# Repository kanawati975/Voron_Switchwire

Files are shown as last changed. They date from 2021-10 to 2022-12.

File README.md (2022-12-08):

# VORON SWITCHWIRE
## This is a Conversion **and** few Upgrades to VSW, for those who has 2020 and 2040 Aluminum Extrusion Profile.

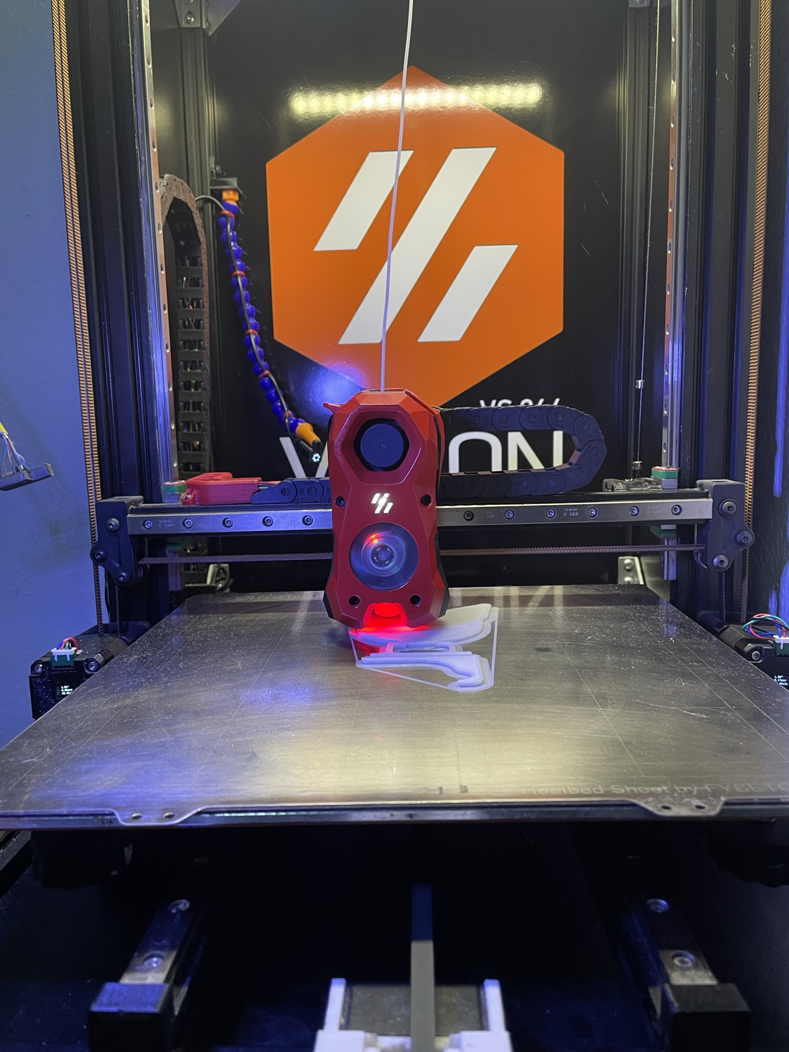
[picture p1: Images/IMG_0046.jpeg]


All of this Repo contents are related to the Voron Switchwire and conversions/Mods. 

## Features and Specifications of my VSW
My Switchwire is a conversion from Geeetech A30 Printer, which is almost identical to the 12V good old Creality CR-10, built with 2020 and 2040 Aluminum Extrusion Profiles. What makes it special is:
- Automated Remote Power Control (via Relays, controlled by the Raspberry Pi from the GUI)
- Dual linear Rails with four MGN12H Blocks on the Y Axis.
- Maximum print Volume: 305 x 305 x 350 mm.
- Controller Board BTT SKR-2 at 168MHz.
- Raspberry Pi 3B Rev 1.2
- TMC2130 Silent Drivers on ~~all axis~~ the extruder. All other Axis are driven by Closed-Loop-System. 
- ~~Galileo~~ Clockwork 2 Extruder (Direct Drive).
- ~~Volcano Hotend~~ Standard V6 Nozzle with Ceramic rounded Heater Cartridge.
- 220VAC 750W 310x310 mm Silicone heated Bed (via SSR).
- 310 x 310 mm Heated Build Platform, with a magnetic Spring steel Sheet.
- Auto Bed (mesh) Probing... Well inslated Metal Detection Sensor/Z Probe.
- ~~Filament Rounout Sensor~~.
- Hybrid Chamber Temperature Control (Passive Heating + Active Chamber Cooling + Chamber Temperature Sensor).
- Custom 3D Printed skirt, with dual 8015 silent Fans.
- External dual USB Ports for further connections to the Raspberry Pi.
- Dual Cameras (RaspiCam+USB Cam) for front **and** back view of the Print.


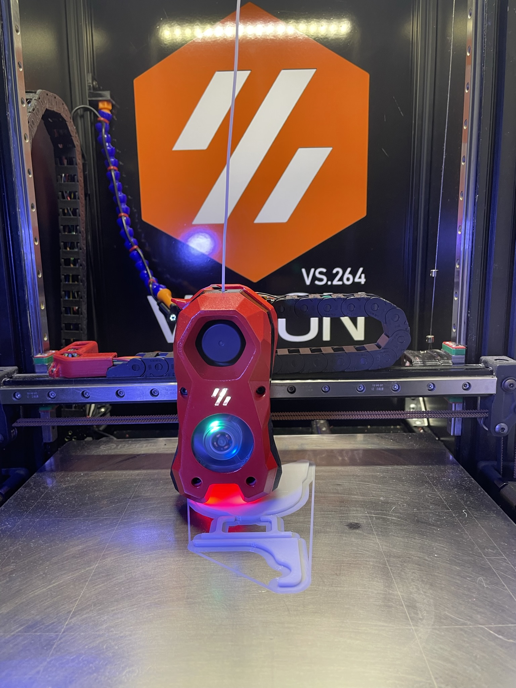
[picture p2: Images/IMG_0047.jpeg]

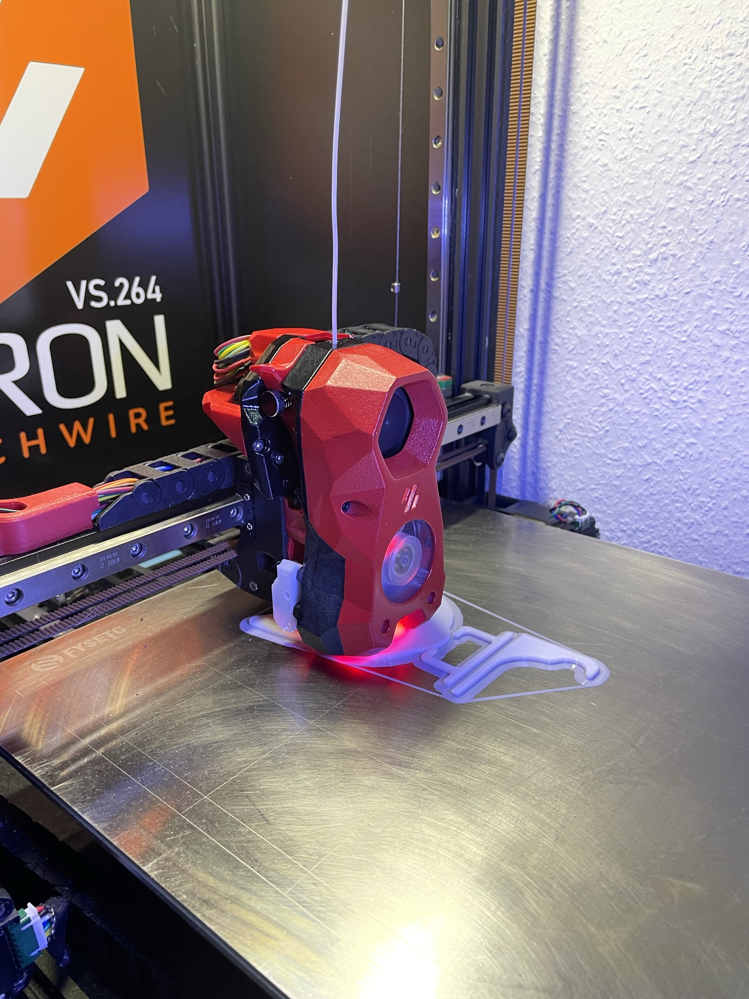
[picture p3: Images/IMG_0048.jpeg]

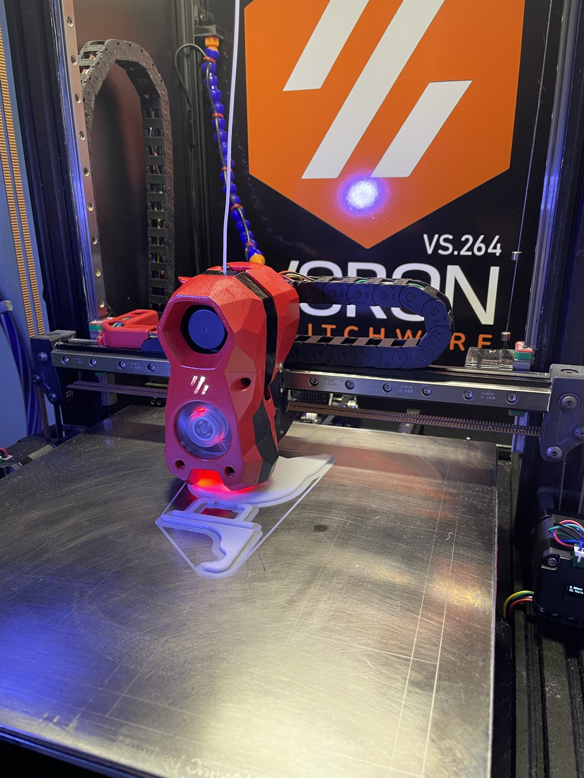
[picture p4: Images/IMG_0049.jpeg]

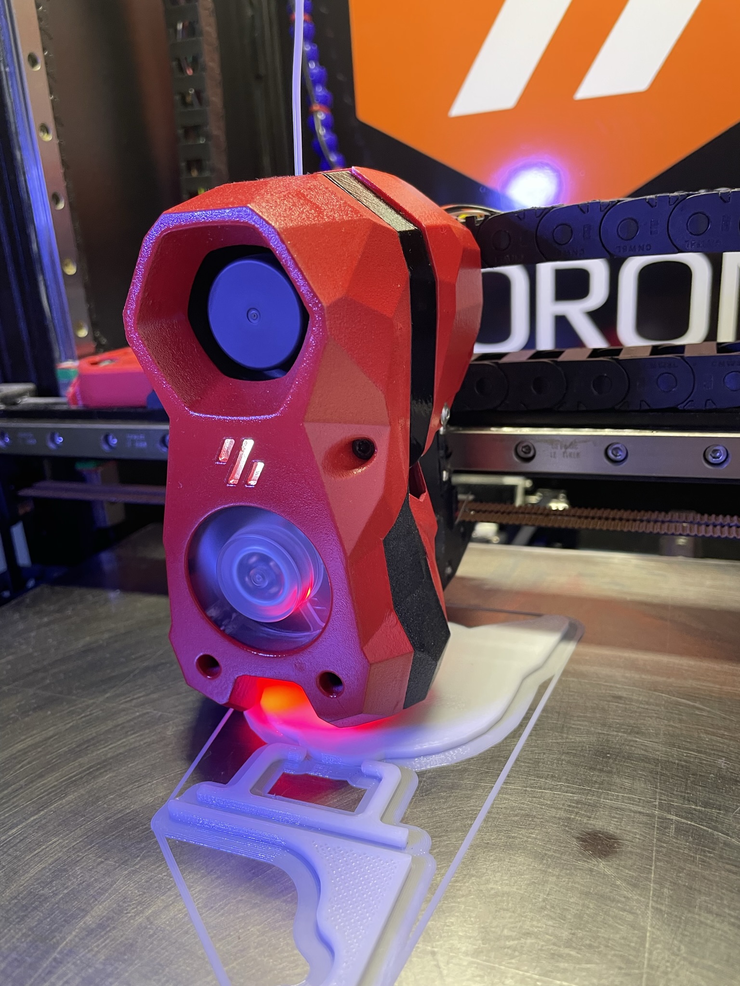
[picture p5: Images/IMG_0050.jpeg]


## What's in this Repository?
[**- BL-Touch Mod**](https://github.com/kanawati975/Voron_Switchwire/tree/main/BL-Touch)

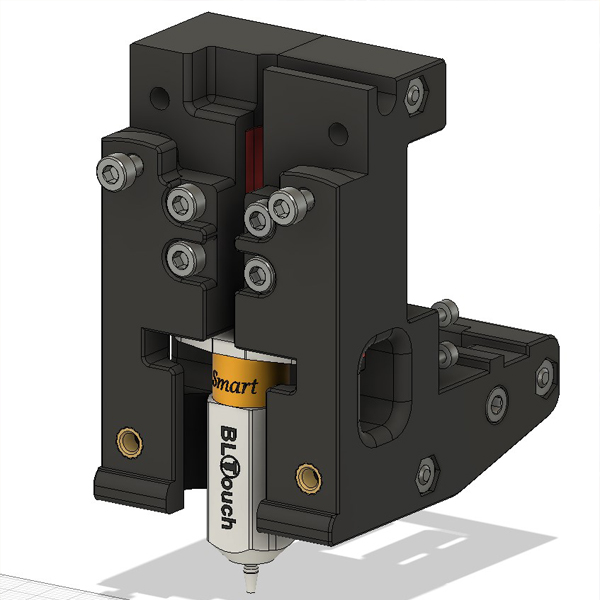
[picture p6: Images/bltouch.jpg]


[**- Emergency Mount**](https://github.com/kanawati975/Voron_Switchwire/tree/main/Emergency%20Mount/STL)

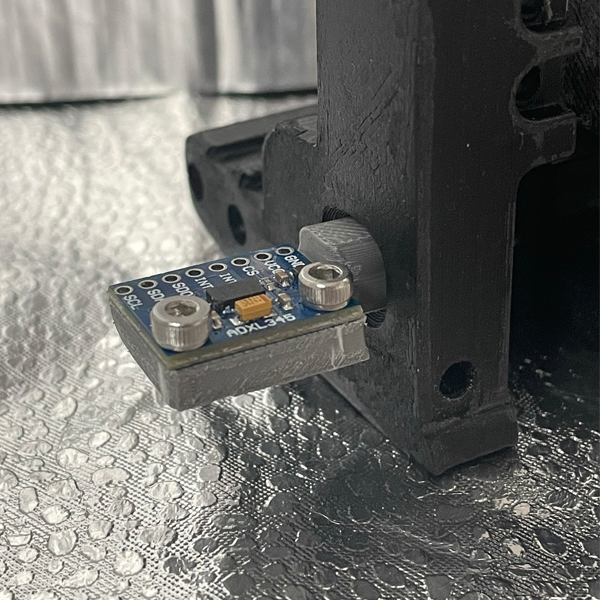
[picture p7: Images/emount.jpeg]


[**- Counterweight Key-Bak Alternative**](https://github.com/kanawati975/Voron_Switchwire/tree/main/Key-Bak)

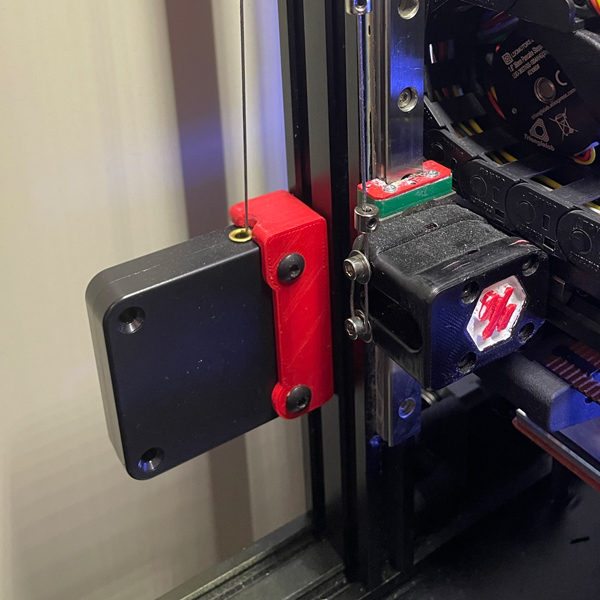
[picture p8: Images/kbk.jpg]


[**- Raspberry pi Camera Mount**](https://github.com/kanawati975/Voron_Switchwire/tree/main/Pi-Cam)

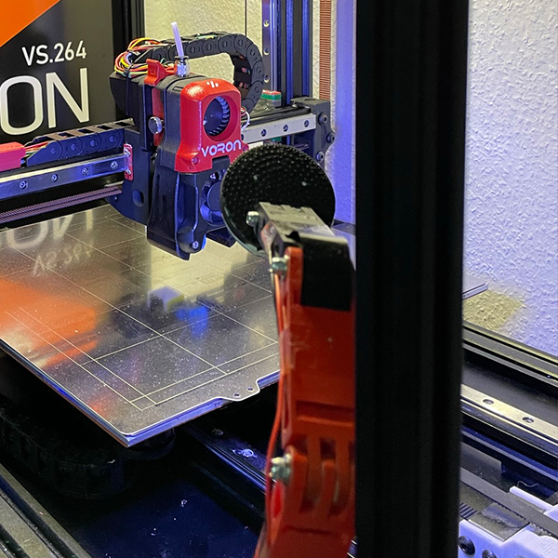
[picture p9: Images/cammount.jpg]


[**- How to install Samba, to access your Pi's contents (Klipper directory) from Windows Explorer.**](https://github.com/kanawati975/Voron_Switchwire/blob/main/Samba/How%20to%20install%20samba.txt)
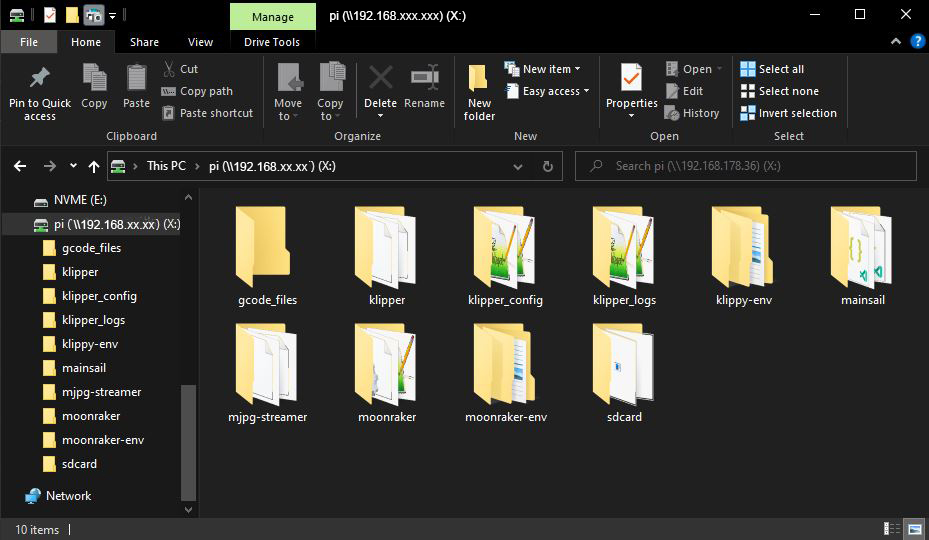
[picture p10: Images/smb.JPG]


[**- Sample configuration for Klipper on SKR-2 Controller Board**](https://github.com/kanawati975/Voron_Switchwire/tree/main/configuration/Klipper)

[**- Sample configuration for Marlin on SKR-2 Controller Board**](https://github.com/kanawati975/Voron_Switchwire/tree/main/configuration/Marlin)

# CONVERSION MODS:
[**- X/Z Motors Mount for the 2020 and 2040 Aluminum Extrusion Profile**](https://github.com/kanawati975/Voron_Switchwire/tree/main/Motor%20Mount)

[**- Upper Belt path / X and Z Blocks**](https://github.com/kanawati975/Voron_Switchwire/tree/main/Upper_XZ_Blocks)

[**- Modified Toolhead for the E3D Volcano**](https://github.com/kanawati975/Voron_Switchwire/tree/main/Volcano_Toolhead)

[**- Modified X Gantry Blocks/Carriers**](https://github.com/kanawati975/Voron_Switchwire/tree/main/XY_Gantry_Blocks)

[**- Modified Headless Front Grill (AKA Skirt) with single Push Button**](https://github.com/kanawati975/Voron_Switchwire/tree/main/Headless%20Skirt)

# USEFUL MACROS:
A collection of the most used or most useful Macros. 
#### All credit goes to the creators of those Macros.

[**- Start Print**](https://github.com/kanawati975/Voron_Switchwire/blob/main/configuration/Klipper/Read.md#start_print)

[**- End Print**](https://github.com/kanawati975/Voron_Switchwire/blob/main/configuration/Klipper/Read.md#end_print)

[**- Prime Line**](https://github.com/kanawati975/Voron_Switchwire/blob/main/configuration/Klipper/Read.md#prime-line)

[**- Park Toolhead**](https://github.com/kanawati975/Voron_Switchwire/blob/main/configuration/Klipper/Read.md#park-toolhead)

[**- Bed Mesh Calibrate (AKA G29)**](https://github.com/kanawati975/Voron_Switchwire/blob/main/configuration/Klipper/Read.md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)

[**- Cancel/Abort Print**](https://github.com/kanawati975/Voron_Switchwire/blob/main/configuration/Klipper/Read.md#cancel_print)

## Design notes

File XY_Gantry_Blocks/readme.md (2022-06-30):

# VERY IMPORTANT #

## You need M5 screws that is no longer than 33mm. Either shorten the screws or use a shimm or washers. ##
Using M5x35 will result a wabbly Gantry

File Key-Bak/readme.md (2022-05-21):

# Counterweight Alternative

While looking for an alternative for the Counterweight (AKA Key-Bak) I stumbled upon this Product
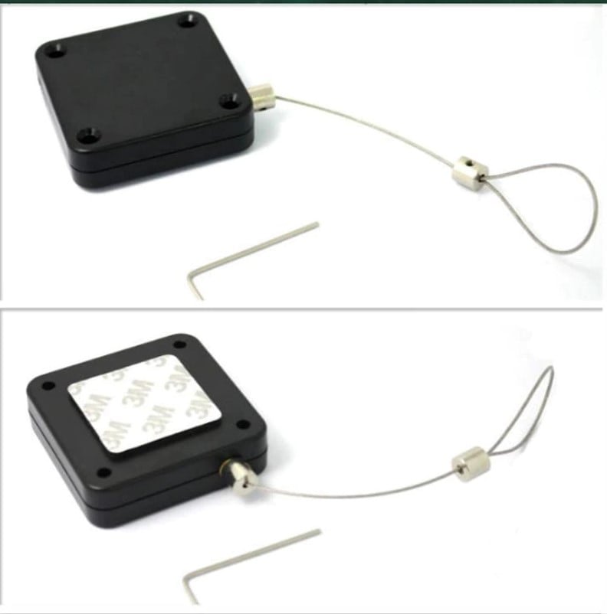
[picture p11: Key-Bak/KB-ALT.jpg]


https://www.aliexpress.com/item/4001346125084.html

## Make sure to choose the 1100G because it has better pulling force.

I've ordered one and it's much easier to mount, and also the tension strength is better AND much cheaper.
If you're sourcing parts for the Switchwire or converting your old machine, I'd highly recomend getting this instead.

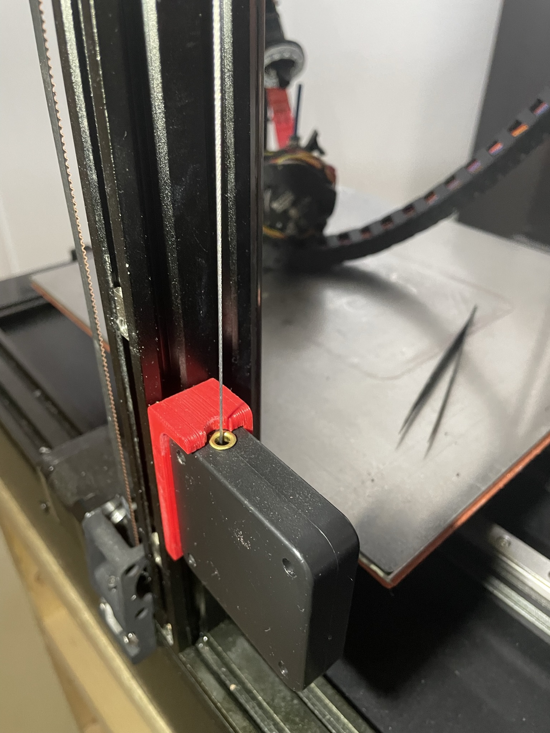
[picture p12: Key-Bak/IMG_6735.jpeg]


# The Mounting Part
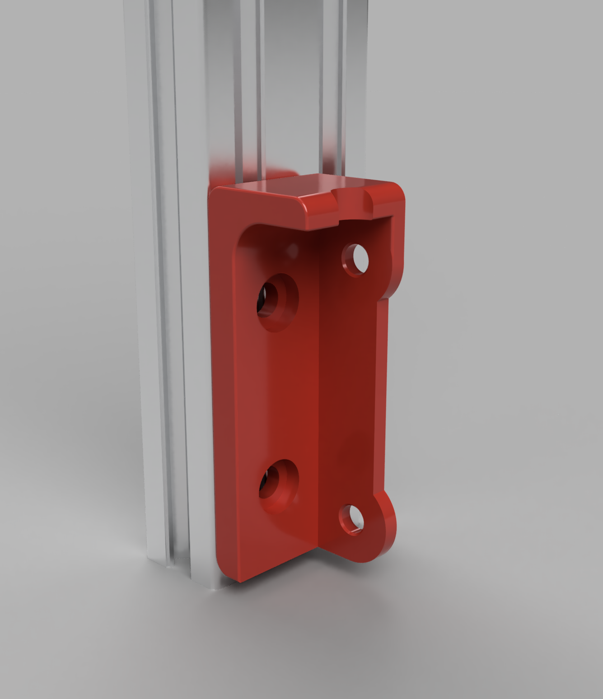
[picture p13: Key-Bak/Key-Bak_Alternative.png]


https://github.com/kanawati975/Voron_Switchwire/blob/main/Key-Bak/Key-Back_Alternative.stl

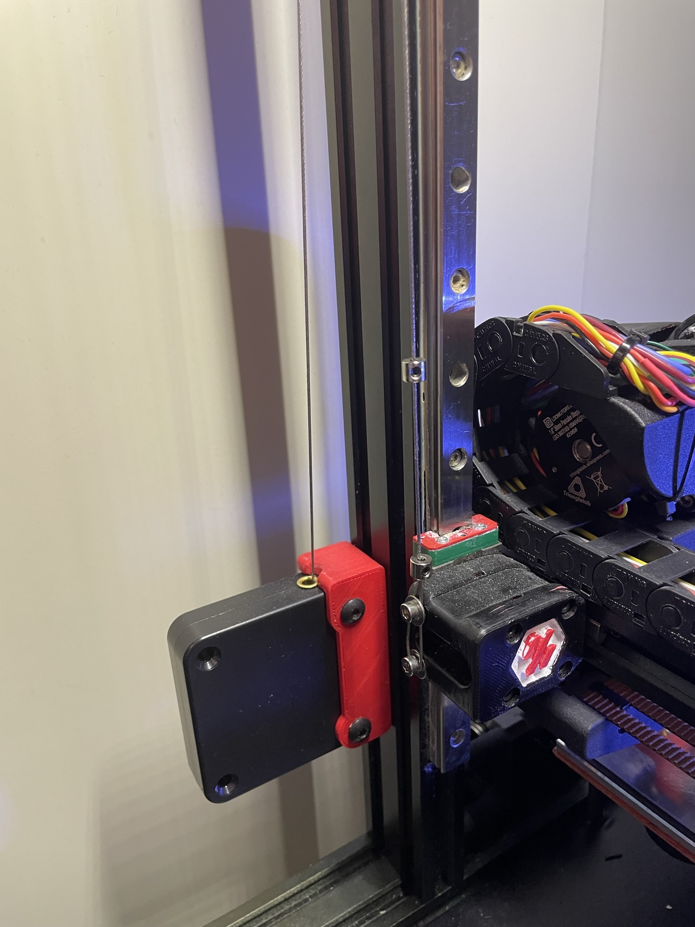
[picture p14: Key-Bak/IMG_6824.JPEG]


## Required Mounting Items:
- Two M5x8
- Two M5 T-Nuts
- Two M5x20

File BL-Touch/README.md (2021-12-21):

This is a Modification to the Afterburner's Tolhead, to accept the touch Sensor (AKA BL-Touch, 3D Touch, etc.)

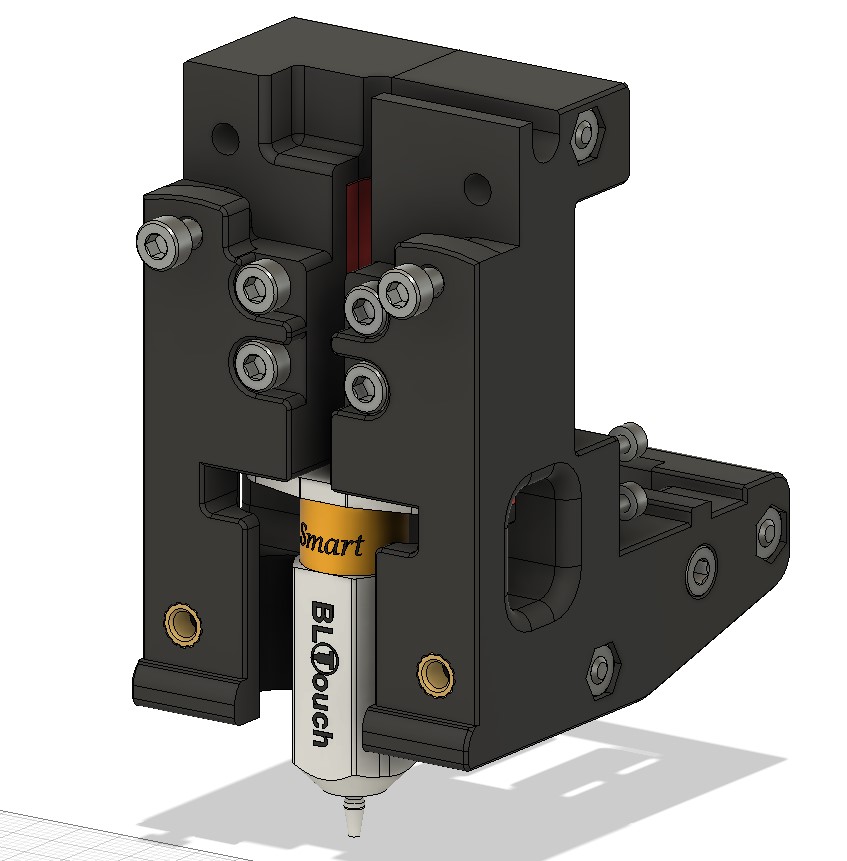
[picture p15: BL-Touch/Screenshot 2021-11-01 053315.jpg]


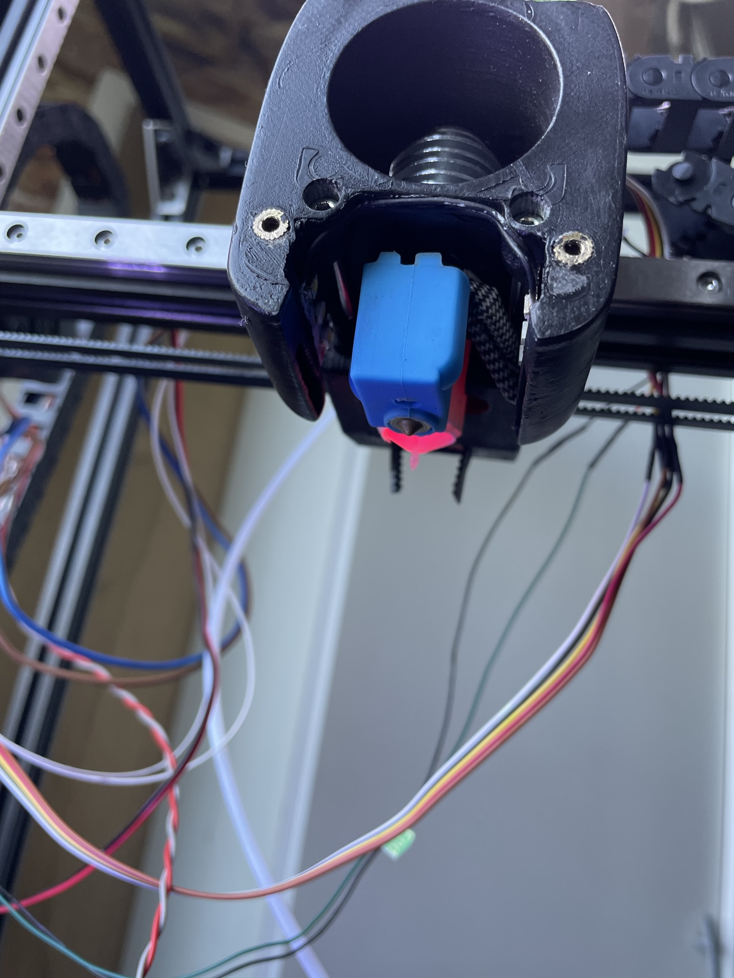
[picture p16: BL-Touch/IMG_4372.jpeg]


For this Mod you can use the two M3x10 screws. 
The M3x20 screws and the Probe Bracket are no longer needed.

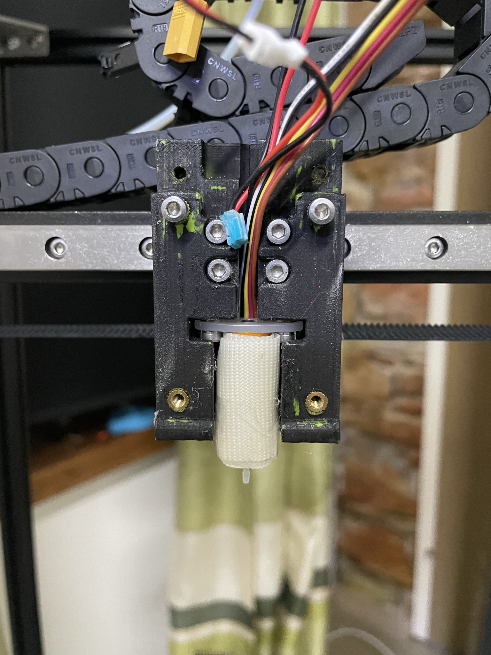
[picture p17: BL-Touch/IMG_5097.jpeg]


It is highly recommened to use any available insulation material to reduce heat on the touch Sensor.

Here's my config senction. Please use it as reference.

```
[bltouch]
sensor_pin: ## Your sensor Pin
control_pin: ## Your data Pin
probe_with_touch_mode: true
pin_up_reports_not_triggered: true
pin_up_touch_mode_reports_triggered: true
stow_on_each_sample: False 
x_offset: 0.0
y_offset: -24
z_offset: 0
speed: 5
lift_speed: 1
samples: 1
sample_retract_dist: 10
samples_result: average
```

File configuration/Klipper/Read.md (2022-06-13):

# Tips:

Here is some help about the configuration parameters, and some useful Macros. 
You can put them all together in printer.cfg file, or you can separate them in different files 
If you decided to make separate files, make sure to include ```file.name``` in the main printer.cfg file.
For macros, it's very common to add ```include macros.cfg``` in the printer config file.

## Useful Macros:
**Disclaimer:** I did not create the Macros. **All credit goes to the creators**

## Park Toolhead:
This Macro is very useful and can be used with a lot of other macros, such as End_Print, Filament_Change, Cancel_Print, etc.
It will lift the Nozzle a little, to avoid collision, then moves to the right, and the bed will go forward.
```
[gcode_macro PARK_TOOLHEAD]
description: Script to park the ToolHead
gcode:
     {% set x_park = printer.toolhead.axis_maximum.x|float - 5.0 %}
     {% set y_park = printer.toolhead.axis_maximum.y|float - 5.0 %}
     {% set max_z = printer.toolhead.axis_maximum.z|float %}
     {% set act_z = printer.toolhead.position.z|float %}
     {% if act_z < (max_z - 10) %}
       {% set z_safe = 2.0 %}
     {% else %}
       {% set z_safe = max_z - act_z %}
     {% endif %}
     G91
     G1 Z{z_safe +10} F900
     G90
     G0 X{x_park} Y{y_park} F6000
     G91
```
## Bed Probe / Mesh Leveling:
This macro will clear any previous mesh saved, and create a new mesh, then save it.
```
[gcode_macro G29]
gcode:
  G28			#Home All Axes
  G90
  BED_MESH_PROFILE REMOVE=default
  BED_MESH_PROFILE REMOVE=default_new
  BED_MESH_CLEAR
  BED_MESH_CALIBRATE
  BED_MESH_PROFILE SAVE=default_new
  SAVE_CONFIG
```

## Prime Line
This macro will create a line at the front of the bed. Basically it will prime the Nozzle and remove any excess Filament.
**Note:** Don't forget to add the Macro's Name to the Print_Start. If you want to customize the prime line, you can by adding the options to the Print_Start macro
```PRIME_LINE XPAD=10 YPAD=10 LENGTH=250 PRINT_SPEED=20 TRAVEL_SPEED=100 PURGE=15 RETRACT=1 EXTRUSION_MULTIPLIER=1.2 PRINT_HANDLE=1 HANDLE_FAN=100```

```
[gcode_macro PRIME_LINE]
description: Print an easy to remove parametric extruder priming line with a built-in handle.
gcode:
    # settings
    {% set line = {
      'x_padding'      : params.XPAD|default(10)|float,  # left/right padding around the bed the line can't print into
      'y_padding'      : params.YPAD|default(10)|float,  # top/bottom padding around the bed the line can't print into
      'initial_purge'  : params.PURGE|default(8)|int,   # mm of filament to purge before printing. set to 0 to disable
      'retract_after'  : params.RETRACT|default(1)|int, # mm of filament to recract after printing. set to 0 to disable
      'length'         : params.LENGTH|default(200)|int, # mm the length of the line
      'print_speed'    : params.PRINT_SPEED|default(20)|int,
      'travel_speed'   : params.TRAVEL_SPEED|default(100)|int,
      'extr_multi'     : params.EXTRUSION_MULTIPLIER|default(1.25)|float,  # apply to prime lines
      'overlap_percent': 80, # how much prime lines overlap each other
    } %}
    {% set handle = {
      'do_print'    : params.PRINT_HANDLE|default(1)|int,  # set to 0 to disable printing the handle
      'fan_percent' : params.HANDLE_FAN|default(100)|int,   # without fan the handle is too small and melty to print upright
      'width'       : 5.0,
      'height'      : 5.0,
      'move_away'   : 60   # how much to move the toolhead away from the printed handle once done. set 0 to disable
    } %}
    # sanity check and computed variables
    {% set max_x, max_y, nozzle_diameter = printer.toolhead.axis_maximum.x|float, printer.toolhead.axis_maximum.y|float, printer.configfile.config['extruder'].nozzle_diameter|float %}
    {% set _ = line.update({'width': nozzle_diameter * 1.25, 'height': nozzle_diameter / 2, 'length': [line.length, max_x - 2 * line.x_padding - 2]|min}) %}
    {% set _ = line.update({'e_per_mm': line.extr_multi * (line.width * line.height) / (3.1415 * (1.75/2)**2), 'x_start': max_x / 2 - line.length / 2, 'y_start': line.y_padding})  %}
    SAVE_GCODE_STATE NAME=STATE_PRIME_LINE
    M117 Prime Line
    G90 # absolute positioning
    G0 X{line.x_start} Y{line.y_start + (handle.width / 2)|int + 1} Z{line.height} F{line.travel_speed * 60} # move to starting position
    G91 # relative positioning
    G1 E{line.initial_purge} F{5 * 60} # extrude at ~12mm3/sec
    G0 F{line.print_speed * 60} # set print speed
    G1 X{line.length} E{line.length * line.e_per_mm} # print forward line
    G0 Y{line.width * line.overlap_percent / 100} # overlap forward line
    G1 X-{line.length / 2} E{(line.length / 2) * line.e_per_mm}  # print backward line for half the length
    # print a handle for easy removal
    {% if handle.do_print != 0 and handle.width != 0 and handle.height != 0 %}
      G0 X{handle.width} Y{handle.width / 2} # move into position for printing handle
      {% set saved_fan_speed = (printer['fan'].speed * 256)|int %}
      M106 S{((handle.fan_percent / 100) * 256)|int} # set part fan to desired speed
      {% for _ in range((line.height * 1000)|int, (handle.height * 1000)|int, (line.height * 1000)|int) %} # loop however many cycles it takes to print required handle height
        G1 Y{loop.cycle(-1.0, 1.0) * handle.width} E{handle.width * line.e_per_mm} # handle layer
        G0 X-{line.width * 0.2} Z{line.height} # move up and shift the layer to make the handle sloping
      {% endfor %}
      M106 S{saved_fan_speed} # restore previous part fan speed
    {% endif %}
    G1 E-{line.retract_after} F{50 * 60} # retract ar 50mm/sec after printing
    G0 Y{handle.move_away} F{line.travel_speed * 60}
    M117
    RESTORE_GCODE_STATE NAME=STATE_PRIME_LINE
```

## START_PRINT
This is the most useful/most important Macro. **It must be added to the Slicer**
### SuperSlicer:
In Printer Tab, Custom G-code section, add the follwing line to Start G-code:

```START_PRINT HOTEND={first_layer_temperature} BED={first_layer_bed_temperature}```

Remember to change **HOTEND** and **BED** to what you have defined in printer.cfg

```
[gcode_macro START_PRINT]
gcode: 
    M106 S0
    {% set BED = params.BED|int %}
    {% set HOTEND = params.HOTEND|int %}
    SET_HEATER_TEMPERATURE HEATER=heater_bed TARGET={BED}        
    TEMPERATURE_WAIT SENSOR=heater_bed MINIMUM={BED}    
    SET_HEATER_TEMPERATURE HEATER=extruder TARGET={HOTEND}
    TEMPERATURE_WAIT SENSOR=extruder MINIMUM={HOTEND}
    {% if "xyz" not in printer.toolhead.homed_axes %}
        G28
    {% endif %}
    BED_MESH_PROFILE LOAD=default #Loading the saved bed mesh Profile.
    M117 Commencing Prime Line
    PRIME_LINE XPAD=10 YPAD=10 LENGTH=250 PRINT_SPEED=20 TRAVEL_SPEED=100 PURGE=15 RETRACT=1 EXTRUSION_MULTIPLIER=1.2 PRINT_HANDLE=1 HANDLE_FAN=100
 ```

## END_PRINT
This is the second most useful/most important Macro. **It must be added to the Slicer**
### SuperSlicer / Cura:
In Printer Tab, Custom G-code section, simply add the follwing line to End G-code:
```END_PRINT```

```
[gcode_macro END_PRINT]
description: Print job ending Protocol
gcode:
     G92 E0
     G1 E-5 F200
     PARK_TOOLHEAD
     TURN_OFF_HEATERS
     M106 S0
     SDCARD_RESET_FILE
     M18
     M117 Printing Aborted!
```

## CANCEL_PRINT
This Macro will interrupt the current Print Job. No need to add it to any Slicer.

```
[gcode_macro CANCEL_PRINT]
description: Cancel the actual running print
rename_existing: ABORT_PRINT
gcode:
    PARK_TOOLHEAD
    TURN_OFF_HEATERS
    M106 S0
    SDCARD_RESET_FILE
    M18
    M117 Printing Aborted!
```

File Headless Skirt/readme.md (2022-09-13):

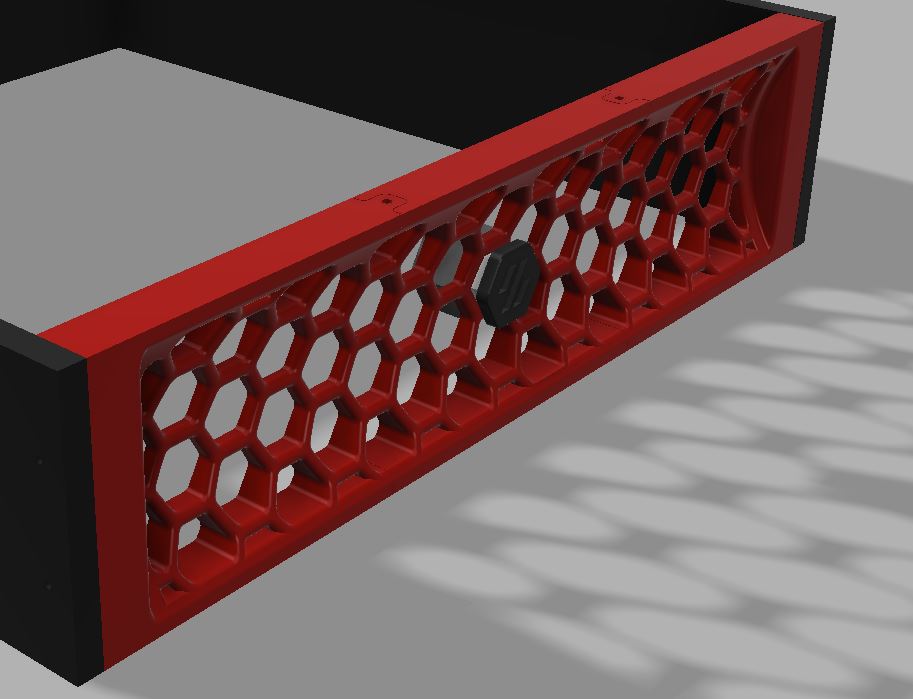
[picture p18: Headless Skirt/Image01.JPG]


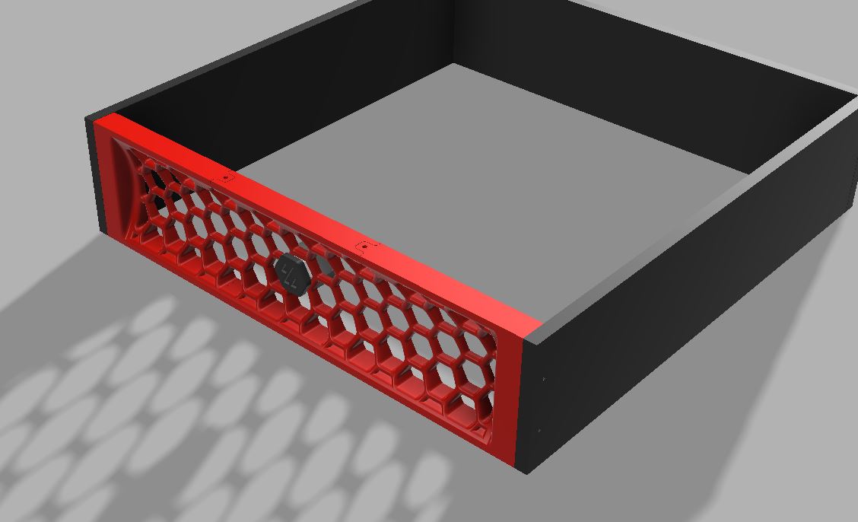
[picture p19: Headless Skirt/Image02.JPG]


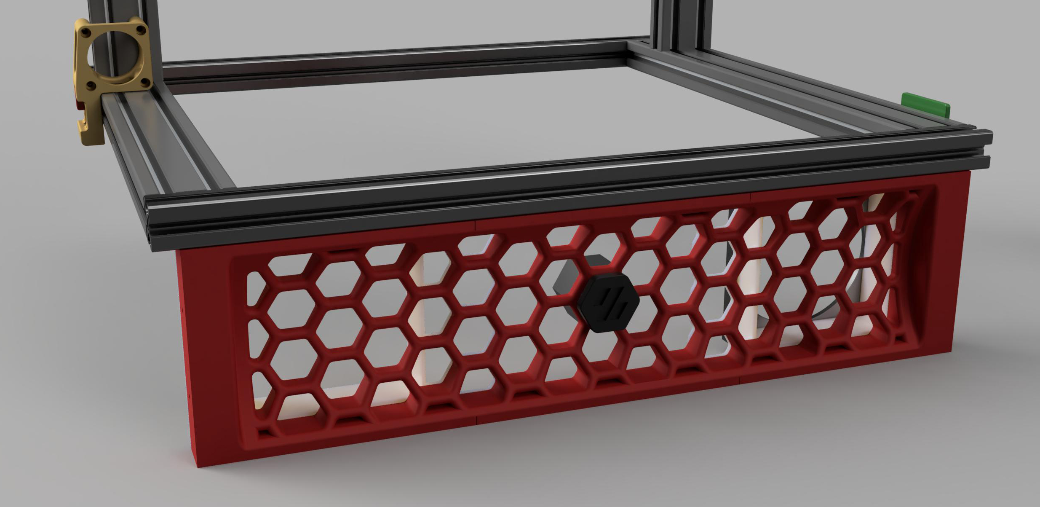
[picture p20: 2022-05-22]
Images/Face_Grill_Design.jpg

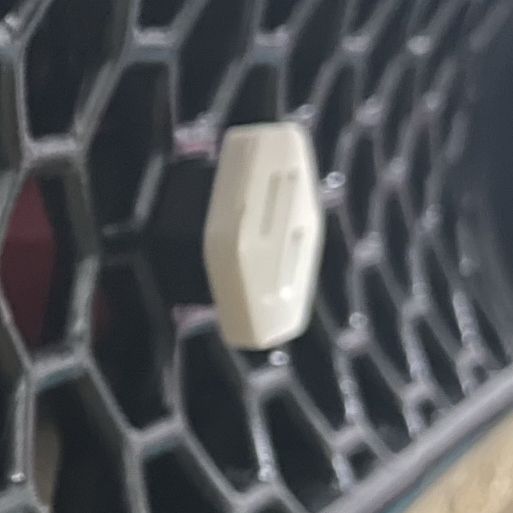
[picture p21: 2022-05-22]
Images/whatever.jpg

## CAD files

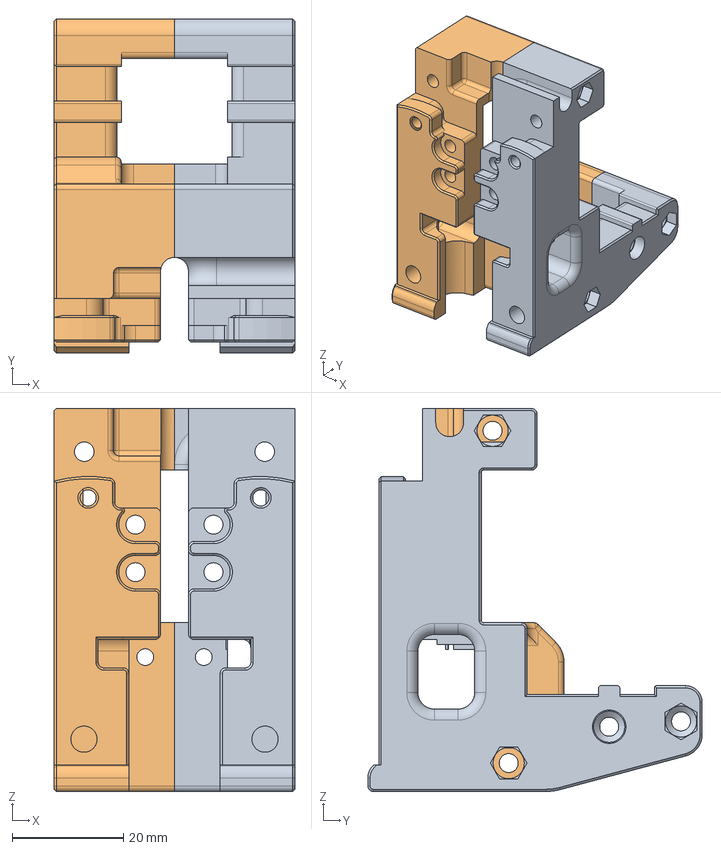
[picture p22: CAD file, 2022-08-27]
BL-Touch/BL_Touch.step
43.2 x 60.0 x 68.8 mm

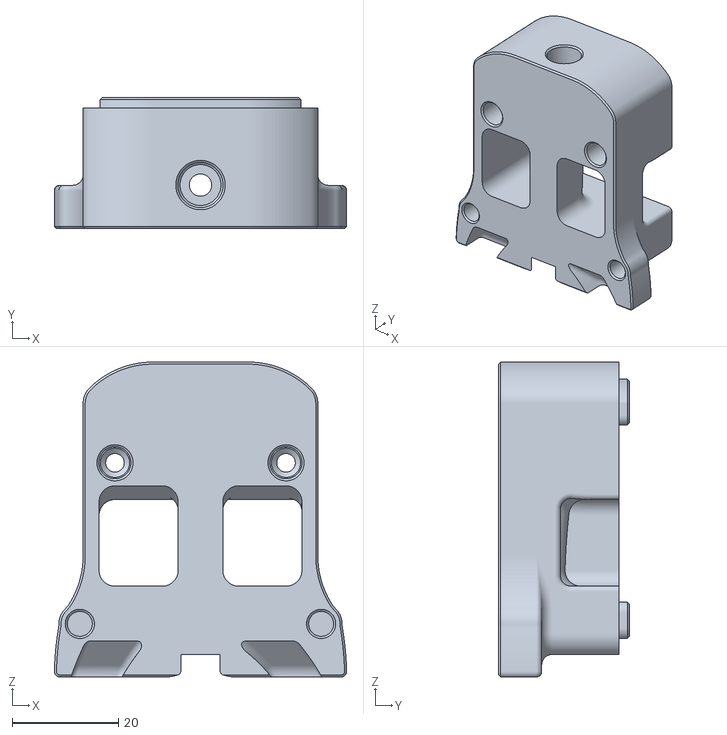
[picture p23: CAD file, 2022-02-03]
Bowden/bowden_adapter_front.stl
55.0 x 24.7 x 59.3

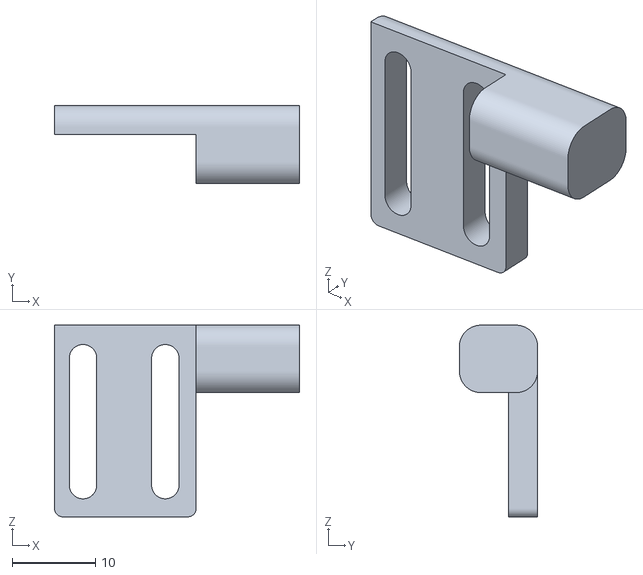
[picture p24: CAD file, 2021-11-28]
Emergency Mount/STL/Touch_Mount.stl
29.4 x 9.40 x 23.0

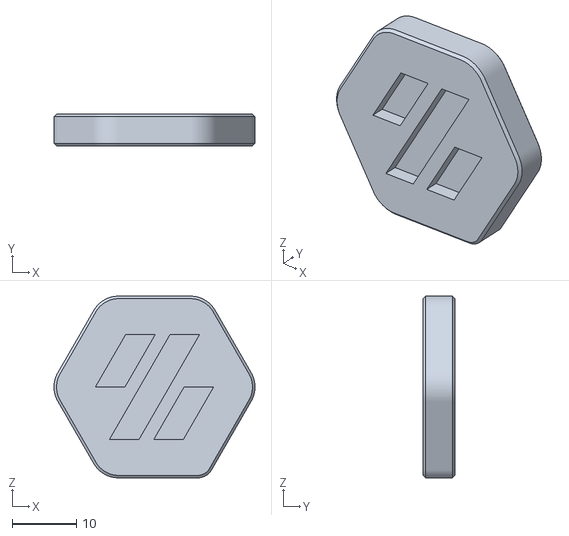
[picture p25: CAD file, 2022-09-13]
Headless Skirt/Button.stl
31.4 x 5.00 x 28.4

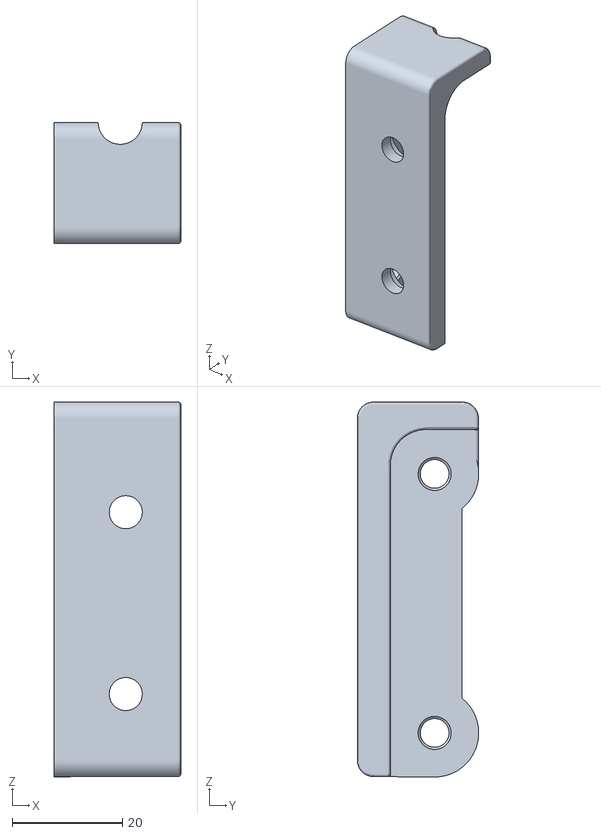
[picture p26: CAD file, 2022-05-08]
Key-Bak/Key-Back_Alternative.stl
23.0 x 22.0 x 68.1

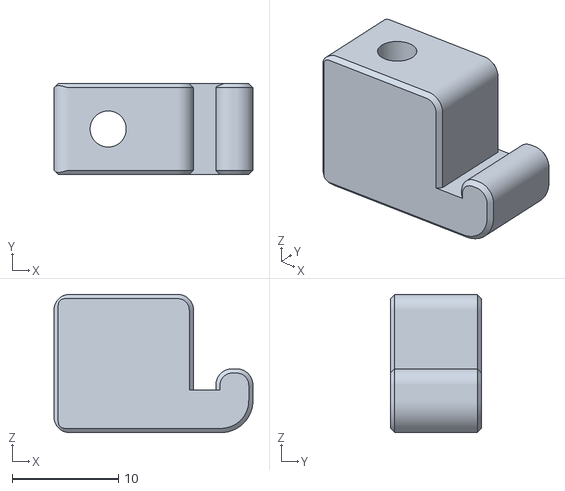
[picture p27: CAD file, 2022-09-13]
Motor Mount/[b]_xz_tensioner.stl
18.7 x 8.60 x 13.0

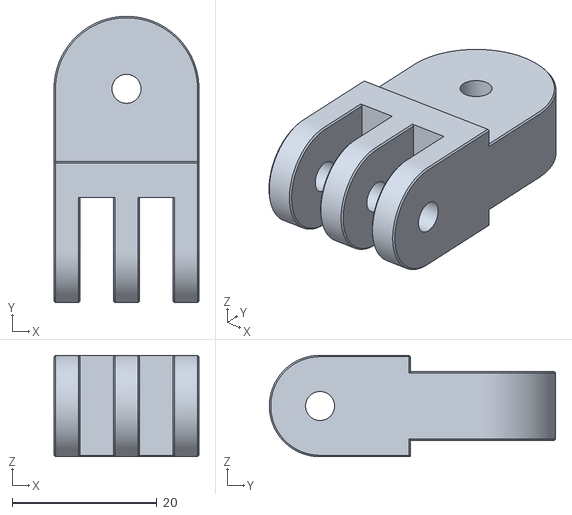
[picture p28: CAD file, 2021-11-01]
Pi-Cam/Joint01.stl
20.0 x 39.5 x 14.0

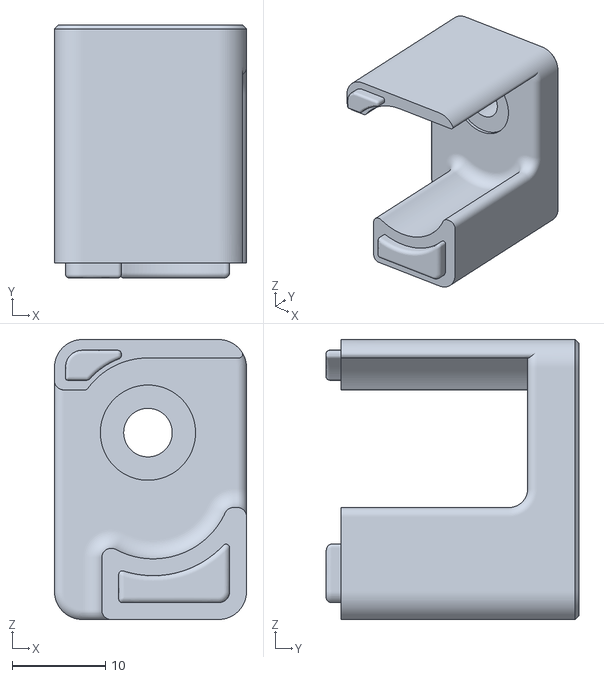
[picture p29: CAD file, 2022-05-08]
Upper_XZ_Blocks/Bearings_Mount_Right.stl
20.6 x 27.1 x 30.0

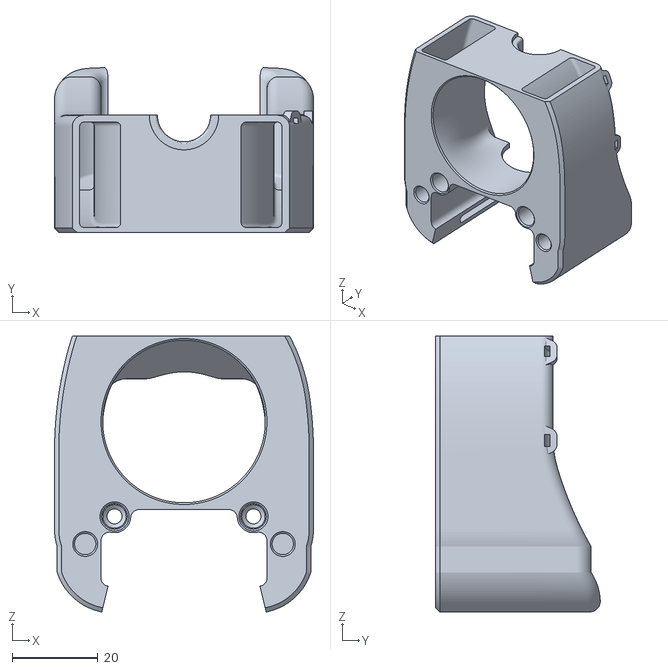
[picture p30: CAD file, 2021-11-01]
Volcano_Toolhead/printhead_front_Volcano.stl
60.6 x 38.5 x 64.6

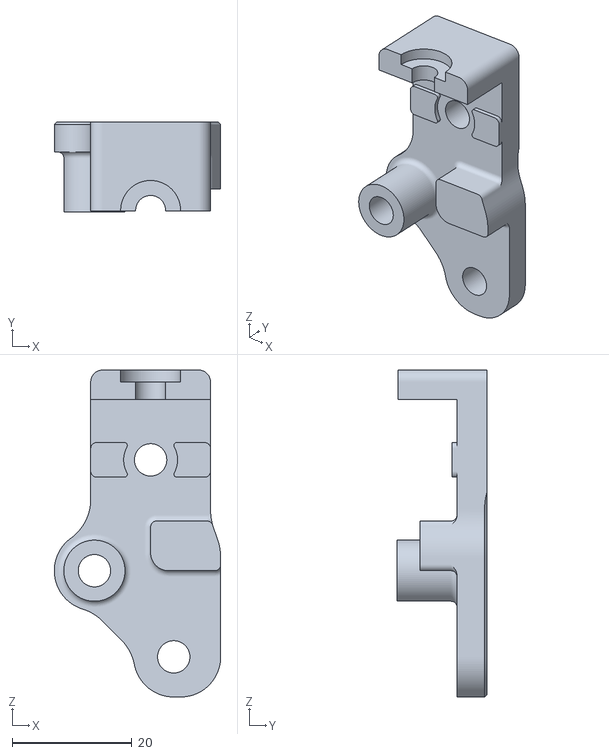
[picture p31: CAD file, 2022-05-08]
XY_Gantry_Blocks/xz_block_right_b.stl
27.8 x 15.0 x 54.6

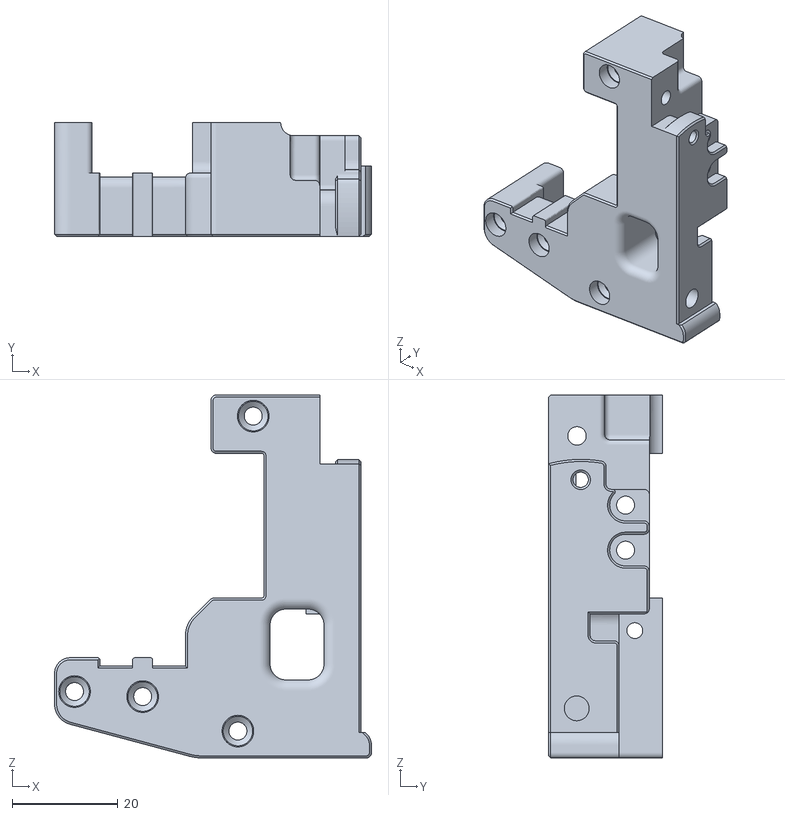
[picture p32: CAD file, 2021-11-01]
BL-Touch/x_carriage_frame_left.stl
60.0 x 21.6 x 68.8

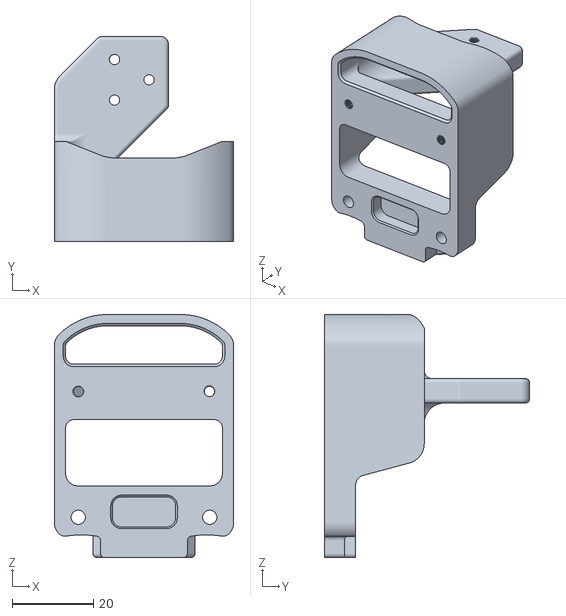
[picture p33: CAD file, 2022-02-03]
Bowden/bowden_module_rear.stl
44.2 x 50.5 x 59.9

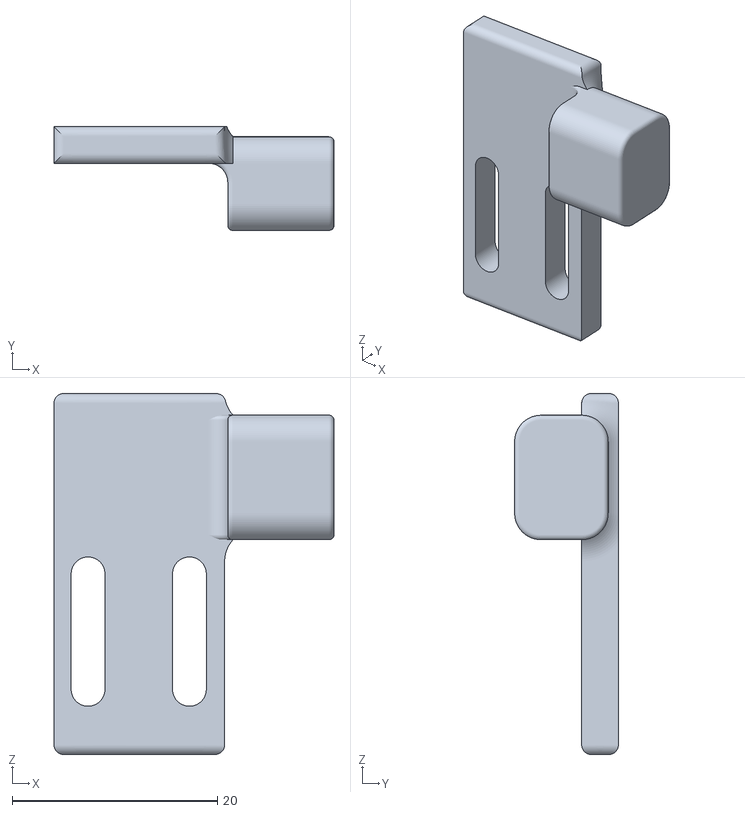
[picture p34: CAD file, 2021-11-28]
Emergency Mount/STL/TL-Q5MC_Mount.stl
27.3 x 10.1 x 35.2

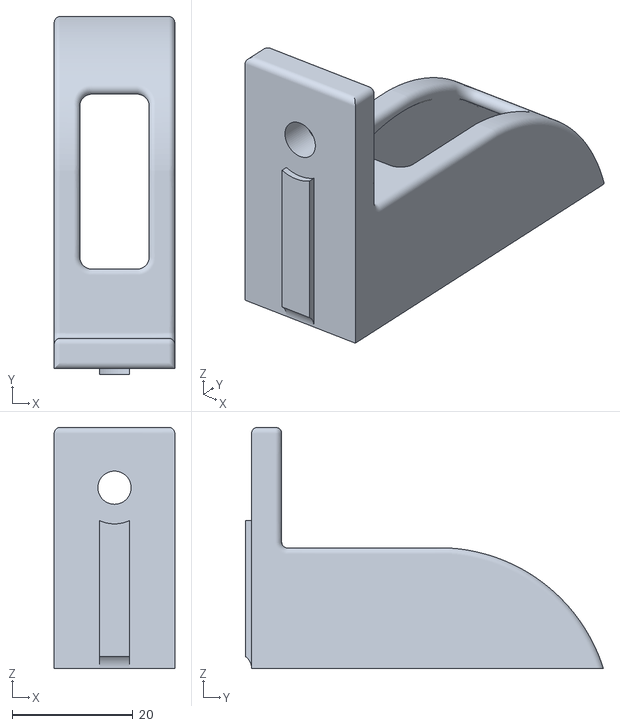
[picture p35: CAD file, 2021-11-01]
Key-Bak/Key-Bak_Mount.stl
20.0 x 59.4 x 40.0

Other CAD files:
Motor Mount/X_motor_mount_a.stl
Pi-Cam/Joint00.stl
Upper_XZ_Blocks/Bearings_Mount_Left.stl
XY_Gantry_Blocks/xz_block_left_a.stl
BL-Touch/x_carriage_frame_right.stl
Emergency Mount/STL/ADXL345_Mount.stl
Emergency Mount/STL/Bltouch.stl
Motor Mount/SW_Motor_Mount.f3d
Motor Mount/X_motor_mount_b.stl
Motor Mount/Z_motor_mount_a.stl
Motor Mount/Z_motor_mount_b.stl
Pi-Cam/4xLink.stl
Pi-Cam/90deg_Adapter.stl
Pi-Cam/Cam_Mount.stl
Upper_XZ_Blocks/XZ_Block_Left.stl
Upper_XZ_Blocks/XZ_Block_Right.stl
XY_Gantry_Blocks/xz_block_left_b.stl
XY_Gantry_Blocks/xz_block_right_a.stl

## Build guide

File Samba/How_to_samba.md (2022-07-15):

## How to install Samba to access and manage your Files on the Raspberry Pi from a windows computer



First, we need to access the Rapberry pi (no matter which Model).

You can use SSH or PuTTY, or directly from windows command Prompt.

`ssh pi@<your.pi.ip.address>`

Now we need to make sure that the system is up to date and then we install the program

`sudo apt-get update`

`sudo apt-get install samba samba-common-bin`

After installation, we need to configure the samba server and define what do we want it to share.

For simplicity, we will just rename the old config file and create our own version instead of a LOT of editing:

```sudo mv /etc/samba/smb.conf /etc/samba/smb.conf.old```

Now we create a new config file:

```sudo nano /etc/samba/smb.conf```

We must add the following contents to the config file we just created. Simply copy them:
```[global]
   workgroup = WORKGROUP  ##Change this to your Workgroup name. By dafault it's WORKGROUP on Windows
   winsupport = yes

#### Debugging/Accounting ####

   log file = /var/log/samba/log.%m
   max log size = 1000
   logging = file
   panic action = /usr/share/samba/panic-action %d

####### Authentication #######

   server role = standalone server
   obey pam restrictions = yes
   unix password sync = yes
   passwd program = /usr/bin/passwd %u
   passwd chat = *Enter\snew\s*\spassword:* %n\n *Retype\snew\s*\spassword:* %n\n *password\supdated\ssuccessfully* .
   pam password change = yes
   map to guest = bad user

############ Misc ############
   usershare allow guests = yes

[homes]
   comment = Home Directories
   browseable = yes
   read only = no
   create mask = 0777
   directory mask = 0777
   valid users = %S

[printers]
   comment = All Printers
   browseable = no
   path = /var/spool/samba
   printable = yes
   guest ok = no
   read only = yes
   create mask = 0777

[print$]
   comment = Printer Drivers
   path = /var/lib/samba/printers
   browseable = yes
   read only = yes
   guest ok = no
   write list = pi, root, @WORKGROUP  ## You may add/change the users or workgroup

[share]
   comment = What do you want to share
   path = /home/pi
   guest ok = yes
   browseable = yes
   printable = yes
   read only = no
   create mask = 0777
   directory mask = 0777
   ```
Save (CTRL+O) and exit (CTRL+X)

Now we need to create a samba user (which is pi) and define its password.

```sudo smbpasswd -a pi```

You will be asked for a password twice. 

**Remember this password, because you will need it to login from windows.**
You could also use the same pi/raspberry defaults.

Now we need to restart the service.

```sudo systemctl restart smbd```

From your Windows Computer, open any explorer window, and click on "This PC" from the left side.
Click on "Map Network Drive" from the top of the Window.

Choose a Letter for the Drive (_I used the Drive Letter X but you can choose any available Drive Letter_), and specify the path to your shared Folder/Directory, which is `//<your.pi.ip.address>` Then click on NEXT

Use the username pi and the Password you created earlier while configuring Samba.

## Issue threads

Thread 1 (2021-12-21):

X and Y offsets not mentioned

Kruze17, 2021-12-21:
what are the x and y offsets for this carriage mod?

kanawati975, 2021-12-21:
@Kruze17 You made an issue on the main Repo. So I don't know what Mod are you talking about,
If you are referring to the Volcano Toolhead, the Offset depends on your Z-Endstop/ Z-Sensor.
Otherwise please specify the Mod you're asking about.

Kruze17, 2021-12-21:
> @Kruze17 You made an issue on the main Repo. So I don't know what Mod are you talking about,
> If you are referring to the Volcano Toolhead, the Offset depends on your Z-Endstop/ Z-Sensor.
> Otherwise please specify the Mod you're asking about.

I am referring the bl touch mod for the x carriage.

kanawati975, 2021-12-21:
@Kruze17 AH okay. It's -24 on the Y

Kruze17, 2021-12-21:
> @Kruze17 AH okay. It's -24 on the Y

Thank you so much. I am closing the issue.

Closed 2021-12-21.

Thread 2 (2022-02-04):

Phaetus BMS not supported(BL Touch mod for x-carriage)

Kruze17, 2022-02-04:
I am using Phaetus BMS as hotend for my switchwire. But after a little time i found out that the probe needle of the BL touch sticks out far more than the nozzle of the hotend itself, as a result the the nozzle can't reach the bed without the bl touch probe needle crashing into the bed.
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

Kruze17, 2022-02-04:
> The original Mod was not made for the Pheatus BMS. It was designed for the E3D Volcano (which I thought that it's the tallest). If you can provide an accurate measurements, I would customize the Mount for your HotEnd's Hight. But first, would you please confirm that the sensor is fastened correctly?

No issues mate. I just wanted to inform you about this. Yes, the sensor is fastened correctly. I will close this issue.

Maccraft123, 2024-04-23:
> The original Mod was not made for the Pheatus BMS. It was designed for the E3D Volcano (which I thought that it's the tallest). If you can provide an accurate measurements, I would customize the Mount for your HotEnd's Hight. But first, would you please confirm that the sensor is fastened correctly?

Hey, I'm also having the same problem with Bltouch sitting too low, though I'm using an E3D Revo Voron. I have measured the distance between the tip of Bltouch and end of nozzle and it's around 3.6mm. Can you modify the mount with Bltouch sitting around 6-7mm higher?

Closed 2022-02-04.

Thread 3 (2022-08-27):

CAD please

strayr, 2022-08-27:
Hi, you've published the STLs, can you share the cad source please? This is a GPL licence compliance issue

kanawati975, 2022-08-27:
Hi,
thank you for your interest.
Which part you're asking for the CAD file?

strayr, 2022-08-27:
the bltouch mod is specifically of interest, but anything that its derived from GPL licenced projects should include your cad source as well as the stl objects.

kanawati975, 2022-08-27:
You can have the [step file from here](https://github.com/kanawati975/Voron_Switchwire/blob/main/BL-Touch/BL_Touch.step).
as fot the other Mods, I don't have the time to export them. I'm not even sure that I still have them.

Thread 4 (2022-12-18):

Problem with XY_Gantry_Blocks

FilamentDave, 2022-12-18:
Hello Kanawati975,

first of all i want to thank you for sharing your work!

I'm converting a GEEETECH A30 Printer to Switchwirw mod and bne happy to use some of your STZL's.

With the four XY Gantry Blocks I have some trouble, because printed the Rollers are in the same places
left and right belt path. At your pictures they are at the correct direction and place.

could you pls check if the provided stls arte correct and if not upload the ones for left which will work?

Many thanks Dave

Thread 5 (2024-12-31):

I know this is an older repo but looking at switching my cr10s to switchwire

DurtymaxNova, 2024-12-31:
Is this everything needed to print or do I need to print more stuff from the actual switchwire repo? Sourcing all the needed hardware is fine just the printables are what is getting difficult.

kanawati975, 2025-01-01:
In all honesty I don't remember. I would suggest a list of parts and you get what's missing here from the original Repo.

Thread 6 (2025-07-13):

not an issue just curious about your closed loop steppers and Klipper

Spinnertebug, 2025-07-13:
Hello thank you for your contribution to the Switchwire!! Your repo is exactly what I needed to take a TronXY X3S from seriously questionable Benchy shaped objects, to actual plastic parts!!

I am curious if you integrated your closed loop stepper motors into Klipper, and if so how you did it. I plan to do so using stand alone stepper mode and step/dir interface. I have little experience with coding besides front end web development but python seems to come easy for me. I know I should have started with C in order to really understand the structure of most programs in order to write more effectively, however it wasn't something I learned until recently.

Anyways thank you in advance for your time any help will be really appreciated and of course thank you again for your contribution to the VSW.

Sincerely,

Keith

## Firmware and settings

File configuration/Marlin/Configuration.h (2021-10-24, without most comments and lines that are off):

#pragma once
#define CONFIGURATION_H_VERSION 02000801
#define STRING_CONFIG_H_AUTHOR "(M. Kanawati)" // Who made the changes.
#define SHOW_CUSTOM_BOOTSCREEN
#define SERIAL_PORT 1
#define BAUDRATE 250000
#define SERIAL_PORT_2 -1
#define BAUDRATE_2 250000   // Enable to override BAUDRATE
  #define MOTHERBOARD BOARD_BTT_SKR_V2_0_REV_B
#define CUSTOM_MACHINE_NAME "Switchwire"
#define EXTRUDERS 1
#define DEFAULT_NOMINAL_FILAMENT_DIA 1.75
#define TEMP_SENSOR_0 1
#define TEMP_SENSOR_1 0
#define TEMP_SENSOR_2 0
#define TEMP_SENSOR_3 0
#define TEMP_SENSOR_4 0
#define TEMP_SENSOR_5 0
#define TEMP_SENSOR_6 0
#define TEMP_SENSOR_7 0
#define TEMP_SENSOR_BED 1
#define TEMP_SENSOR_PROBE 0
#define TEMP_SENSOR_CHAMBER 0
#define TEMP_SENSOR_COOLER 0
#define DUMMY_THERMISTOR_998_VALUE  25
#define DUMMY_THERMISTOR_999_VALUE 100
#define MAX_REDUNDANT_TEMP_SENSOR_DIFF 10
#define TEMP_RESIDENCY_TIME         10  // (seconds) Time to wait for hotend to "settle" in M109
#define TEMP_WINDOW                  1  // (°C) Temperature proximity for the "temperature reached" timer
#define TEMP_HYSTERESIS              3  // (°C) Temperature proximity considered "close enough" to the target
#define TEMP_BED_RESIDENCY_TIME     10  // (seconds) Time to wait for bed to "settle" in M190
#define TEMP_BED_WINDOW              2  // (°C) Temperature proximity for the "temperature reached" timer
#define TEMP_BED_HYSTERESIS          5  // (°C) Temperature proximity considered "close enough" to the target
#define TEMP_CHAMBER_RESIDENCY_TIME 10  // (seconds) Time to wait for chamber to "settle" in M191
#define TEMP_CHAMBER_WINDOW          1  // (°C) Temperature proximity for the "temperature reached" timer
#define TEMP_CHAMBER_HYSTERESIS      3  // (°C) Temperature proximity considered "close enough" to the target
#define HEATER_0_MINTEMP   5
#define HEATER_1_MINTEMP   5
#define HEATER_2_MINTEMP   5
#define HEATER_3_MINTEMP   5
#define HEATER_4_MINTEMP   5
#define HEATER_5_MINTEMP   5
#define HEATER_6_MINTEMP   5
#define HEATER_7_MINTEMP   5
#define BED_MINTEMP        5
#define CHAMBER_MINTEMP    5
#define HEATER_0_MAXTEMP 300
#define HEATER_1_MAXTEMP 275
#define HEATER_2_MAXTEMP 275
#define HEATER_3_MAXTEMP 275
#define HEATER_4_MAXTEMP 275
#define HEATER_5_MAXTEMP 275
#define HEATER_6_MAXTEMP 275
#define HEATER_7_MAXTEMP 275
#define BED_MAXTEMP      130
#define CHAMBER_MAXTEMP  75
#define HOTEND_OVERSHOOT 15   // (°C) Forbid temperatures over MAXTEMP - OVERSHOOT
#define BED_OVERSHOOT    15   // (°C) Forbid temperatures over MAXTEMP - OVERSHOOT
#define COOLER_OVERSHOOT  2   // (°C) Forbid temperatures closer than OVERSHOOT
#define PIDTEMP
#define BANG_MAX 255     // Limits current to nozzle while in bang-bang mode; 255=full current
#define PID_MAX BANG_MAX // Limits current to nozzle while PID is active (see PID_FUNCTIONAL_RANGE below); 255=full current
#define PID_K1 0.95      // Smoothing factor within any PID loop
  #define PID_EDIT_MENU         // Add PID editing to the "Advanced Settings" menu. (~700 bytes of PROGMEM)
  #define PID_AUTOTUNE_MENU     // Add PID auto-tuning to the "Advanced Settings" menu. (~250 bytes of PROGMEM)
    #define DEFAULT_Kp 55.29
    #define DEFAULT_Ki 10.88
    #define DEFAULT_Kd 70.22
#define PIDTEMPBED
#define MAX_BED_POWER 255 // limits duty cycle to bed; 255=full current
  #define MIN_BED_POWER 0
  #define PID_BED_DEBUG // Sends debug data to the serial port.
  #define DEFAULT_bedKp 133.65
  #define DEFAULT_bedKi 26.31
  #define DEFAULT_bedKd 452.63
#define MAX_CHAMBER_POWER 255 // limits duty cycle to chamber heater; 255=full current
  #define PID_FUNCTIONAL_RANGE 10 // If the temperature difference between the target temperature and the actual temperature
#define PREVENT_COLD_EXTRUSION
#define EXTRUDE_MINTEMP 170
#define PREVENT_LENGTHY_EXTRUDE
#define EXTRUDE_MAXLENGTH 200
#define THERMAL_PROTECTION_HOTENDS // Enable thermal protection for all extruders
#define THERMAL_PROTECTION_BED     // Enable thermal protection for the heated bed
#define COREXZ
#define USE_XMIN_PLUG
#define USE_YMIN_PLUG
#define USE_ZMIN_PLUG
#define ENDSTOPPULLUPS
#define X_MIN_ENDSTOP_INVERTING true // Set to true to invert the logic of the endstop.
#define Y_MIN_ENDSTOP_INVERTING true // Set to true to invert the logic of the endstop.
#define Z_MIN_ENDSTOP_INVERTING true // Set to true to invert the logic of the endstop.
#define X_MAX_ENDSTOP_INVERTING false // Set to true to invert the logic of the endstop.
#define Y_MAX_ENDSTOP_INVERTING false // Set to true to invert the logic of the endstop.
#define Z_MAX_ENDSTOP_INVERTING false // Set to true to invert the logic of the endstop.
#define Z_MIN_PROBE_ENDSTOP_INVERTING false // Set to true to invert the logic of the probe.
#define X_DRIVER_TYPE  TMC2130
#define Y_DRIVER_TYPE  TMC2130
#define Z_DRIVER_TYPE  TMC2130
#define E0_DRIVER_TYPE TMC2130
#define DEFAULT_AXIS_STEPS_PER_UNIT   { 160, 200, 160, 410 } // 592 Steps for M4 Extruder
#define DEFAULT_MAX_FEEDRATE          { 3000, 3000, 3000, 25 }
#define DEFAULT_MAX_ACCELERATION      { 500, 500, 500, 10000 }
#define DEFAULT_ACCELERATION          800    // X, Y, Z and E acceleration for printing moves
#define DEFAULT_RETRACT_ACCELERATION  800    // E acceleration for retracts
#define DEFAULT_TRAVEL_ACCELERATION   800    // X, Y, Z acceleration for travel (non printing) moves
#define CLASSIC_JERK
  #define DEFAULT_XJERK 10.0
  #define DEFAULT_YJERK 10.0
  #define DEFAULT_ZJERK  0.3
#define DEFAULT_EJERK    5.0  // May be used by Linear Advance
#define S_CURVE_ACCELERATION
#define Z_MIN_PROBE_USES_Z_MIN_ENDSTOP_PIN
#define BLTOUCH
#define NOZZLE_TO_PROBE_OFFSET { 0, 24, -4 } // Suppose to be { 0, -24, -3.7 }
#define PROBING_MARGIN 10
#define XY_PROBE_FEEDRATE (110*60)
#define Z_PROBE_FEEDRATE_FAST (6*60)
#define Z_PROBE_FEEDRATE_SLOW (Z_PROBE_FEEDRATE_FAST / 3)
#define Z_CLEARANCE_DEPLOY_PROBE   10 // Z Clearance for Deploy/Stow
#define Z_CLEARANCE_BETWEEN_PROBES  5 // Z Clearance between probe points
#define Z_CLEARANCE_MULTI_PROBE     5 // Z Clearance between multiple probes
#define Z_PROBE_LOW_POINT          -5 // Farthest distance below the trigger-point to go before stopping
#define Z_PROBE_OFFSET_RANGE_MIN -20
#define Z_PROBE_OFFSET_RANGE_MAX 20
#define Z_MIN_PROBE_REPEATABILITY_TEST
#define X_ENABLE_ON 0
#define Y_ENABLE_ON 0
#define Z_ENABLE_ON 0
#define E_ENABLE_ON 0 // For all extruders
#define DISABLE_X false
#define DISABLE_Y false
#define DISABLE_Z false
#define DISABLE_E false             // Disable the extruder when not stepping
#define DISABLE_INACTIVE_EXTRUDER   // Keep only the active extruder enabled
#define INVERT_X_DIR false
#define INVERT_Y_DIR true
#define INVERT_Z_DIR false
#define INVERT_E0_DIR true
#define INVERT_E1_DIR false
#define INVERT_E2_DIR false
#define INVERT_E3_DIR false
#define INVERT_E4_DIR false
#define INVERT_E5_DIR false
#define INVERT_E6_DIR false
#define INVERT_E7_DIR false
#define X_HOME_DIR -1
#define Y_HOME_DIR -1
#define Z_HOME_DIR -1
#define X_BED_SIZE 310
#define Y_BED_SIZE 310
#define X_MIN_POS 0
#define Y_MIN_POS -57.5
#define Z_MIN_POS 0
#define X_MAX_POS X_BED_SIZE
#define Y_MAX_POS Y_BED_SIZE-30
#define Z_MAX_POS 300
#define FILAMENT_RUNOUT_SENSOR
  #define FIL_RUNOUT_ENABLED_DEFAULT true // Enable the sensor on startup. Override with M412 followed by M500.
  #define NUM_RUNOUT_SENSORS   1          // Number of sensors, up to one per extruder. Define a FIL_RUNOUT#_PIN for each.
  #define FIL_RUNOUT_STATE     LOW        // Pin state indicating that filament is NOT present.
  #define FIL_RUNOUT_PULLDOWN           // Use internal pulldown for filament runout pins.
  #define FILAMENT_RUNOUT_SCRIPT "M600"
#define AUTO_BED_LEVELING_BILINEAR
#define DEBUG_LEVELING_FEATURE
  #define ENABLE_LEVELING_FADE_HEIGHT
    #define DEFAULT_LEVELING_FADE_HEIGHT 10.0 // (mm) Default fade height.
  #define SEGMENT_LEVELED_MOVES
  #define LEVELED_SEGMENT_LENGTH 5.0 // (mm) Length of all segments (except the last one)
  #define GRID_MAX_POINTS_X 3
  #define GRID_MAX_POINTS_Y GRID_MAX_POINTS_X
    #define EXTRAPOLATE_BEYOND_GRID
    #define ABL_BILINEAR_SUBDIVISION
      #define BILINEAR_SUBDIVISIONS 3
#define LCD_BED_LEVELING
  #define MESH_EDIT_Z_STEP  0.025 // (mm) Step size while manually probing Z axis.
  #define LCD_PROBE_Z_RANGE 4     // (mm) Z Range centered on Z_MIN_POS for LCD Z adjustment
  #define MESH_EDIT_MENU        // Add a menu to edit mesh points
#define LEVEL_BED_CORNERS
  #define LEVEL_CORNERS_INSET_LFRB { 30, 40, 30, 40 } // (mm) Left, Front, Right, Back insets
  #define LEVEL_CORNERS_HEIGHT      0.0   // (mm) Z height of nozzle at leveling points
  #define LEVEL_CORNERS_Z_HOP       4.0   // (mm) Z height of nozzle between leveling points
  #define LEVEL_CORNERS_LEVELING_ORDER { LF, RF, RB, LB }
#define Z_SAFE_HOMING
  #define Z_SAFE_HOMING_X_POINT X_CENTER  // X point for Z homing
  #define Z_SAFE_HOMING_Y_POINT Y_CENTER  // Y point for Z homing
#define HOMING_FEEDRATE_MM_M { (70*60), (65*60), (4*60) }
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

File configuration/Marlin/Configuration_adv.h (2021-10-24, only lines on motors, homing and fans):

#define E0_AUTO_FAN_PIN PB4
#define E1_AUTO_FAN_PIN -1
#define E2_AUTO_FAN_PIN -1
#define E3_AUTO_FAN_PIN -1
#define E4_AUTO_FAN_PIN -1
#define E5_AUTO_FAN_PIN -1
#define E6_AUTO_FAN_PIN -1
#define E7_AUTO_FAN_PIN -1
#define CHAMBER_AUTO_FAN_PIN -1
#define COOLER_AUTO_FAN_PIN -1
#define COOLER_FAN_PIN -1
#define HOMING_BUMP_DIVISOR { 4, 4, 4 }       // Re-Bump Speed Divisor (Divides the Homing Feedrate)
#define MICROSTEP_MODES { 16, 16, 16, 16, 16, 16 } // [1,2,4,8,16]
  #define BABYSTEP_WITHOUT_HOMING
#define LIN_ADVANCE
  #define LIN_ADVANCE_K 0.656    // Unit: mm compression per 1mm/s extruder speed
#define ADVANCED_PAUSE_FEATURE
  #define ADVANCED_PAUSE_PURGE_FEEDRATE        3  // (mm/s) Extrude feedrate (after loading). Should be slower than load feedrate.
  #define ADVANCED_PAUSE_PURGE_LENGTH         50  // (mm) Length to extrude after loading.
  #define ADVANCED_PAUSE_RESUME_PRIME          0  // (mm) Extra distance to prime nozzle after returning from park.
    #define X_CURRENT       900        // (mA) RMS current. Multiply by 1.414 for peak current.
    #define X_CURRENT_HOME  X_CURRENT  // (mA) RMS current for sensorless homing
    #define X_MICROSTEPS     32        // 0..256
    #define Y_CURRENT       700
    #define Y_CURRENT_HOME  Y_CURRENT
    #define Y_MICROSTEPS     32
    #define Z_CURRENT       900
    #define Z_CURRENT_HOME  Z_CURRENT
    #define Z_MICROSTEPS     32
    #define E0_CURRENT      800
    #define E0_MICROSTEPS    16
    #define CURRENT_STEP_DOWN     20  // [mA]
    #define REPORT_CURRENT_CHANGE
  #define HYBRID_THRESHOLD
  #define X_HYBRID_THRESHOLD     2000  // [mm/s]
  #define X2_HYBRID_THRESHOLD    2000
  #define Y_HYBRID_THRESHOLD     2000
  #define Y2_HYBRID_THRESHOLD    2000
  #define Z_HYBRID_THRESHOLD     2000
  #define Z2_HYBRID_THRESHOLD    2000
  #define Z3_HYBRID_THRESHOLD     300
  #define Z4_HYBRID_THRESHOLD     300
  #define E0_HYBRID_THRESHOLD     2000
  #define E1_HYBRID_THRESHOLD     300
  #define E2_HYBRID_THRESHOLD     300
  #define E3_HYBRID_THRESHOLD     300
  #define E4_HYBRID_THRESHOLD     300
  #define E5_HYBRID_THRESHOLD     300
  #define E6_HYBRID_THRESHOLD     300
  #define E7_HYBRID_THRESHOLD     300
  #define SENSORLESS_HOMING // StallGuard capable drivers only
    #define X_STALL_SENSITIVITY  10
    #define X2_STALL_SENSITIVITY X_STALL_SENSITIVITY
    #define Y_STALL_SENSITIVITY  46
    #define Y2_STALL_SENSITIVITY Y_STALL_SENSITIVITY
    #define IMPROVE_HOMING_RELIABILITY

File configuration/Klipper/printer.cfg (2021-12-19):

############################################
### Tis is a modified Pin-mapping config ###
### For swapping Y and E1 Sockets ##########
############################################

[mcu]
serial: /dev/serial/by-id/usb-Klipper_stm32f407xx_38003D001647393530343239-if00
restart_method: command

[mcu host]
serial: /tmp/klipper_host_mcu

[printer]
kinematics: corexz
max_velocity: 300
max_accel: 1200
max_z_velocity: 100
max_z_accel: 750
max_accel_to_decel: 600
square_corner_velocity: 5

[stepper_x]
step_pin: PE2
dir_pin: PE1
enable_pin: !PE3
microsteps: 16
rotation_distance: 40
full_steps_per_rotation: 200
position_min: 0
position_endstop: 306
position_max: 306
homing_speed: 80
endstop_pin: !PC1 
#endstop_pin:tmc2130_stepper_x:virtual_endstop
homing_retract_dist: 5
homing_retract_speed: 25

[tmc2130 stepper_x]
#spi_speed:
spi_software_sclk_pin: PE15
spi_software_mosi_pin: PE14
spi_software_miso_pin: PA14
cs_pin: PE0
diag1_pin: ^!PC1
driver_IHOLDDELAY: 8
driver_TPOWERDOWN: 0
driver_TBL: 1
driver_TOFF: 4
driver_HEND: 7
driver_HSTRT: 0
driver_PWM_AUTOSCALE: True
driver_PWM_FREQ: 1
driver_PWM_GRAD: 4
driver_PWM_AMPL: 128
sense_resistor: 0.110
run_current: 1
hold_current: 0.60
interpolate: True
stealthchop_threshold: 250
driver_SGT: 17

[stepper_y]
step_pin: PD11
dir_pin: !PD10
enable_pin: !PD13
microsteps: 16
rotation_distance: 32
full_steps_per_rotation: 200
position_min: -50
position_max: 286
homing_speed: 85
#endstop_pin:tmc2130_stepper_y:virtual_endstop
endstop_pin: !PC3
position_endstop: -50
homing_retract_dist: 5
homing_retract_speed: 25

[tmc2130 stepper_y]
#spi_speed:
spi_software_sclk_pin: PE15
spi_software_mosi_pin: PE14
spi_software_miso_pin: PA14
driver_IHOLDDELAY: 8
driver_TPOWERDOWN: 0
driver_TBL: 1
driver_TOFF: 4
driver_HEND: 7
driver_HSTRT: 0
driver_PWM_AUTOSCALE: True
driver_PWM_FREQ: 1
driver_PWM_GRAD: 4
driver_PWM_AMPL: 128
sense_resistor: 0.110
cs_pin: PD12
run_current: 0.75
interpolate: True
stealthchop_threshold: 250
diag1_pin: ^!PA0
driver_SGT: 10


[stepper_z]
step_pin: PA15
dir_pin: PA8
enable_pin: !PD1
rotation_distance: 40
full_steps_per_rotation: 200
microsteps: 16
endstop_pin: probe:z_virtual_endstop
position_max: 320
position_min: -5
homing_speed: 40
homing_retract_dist: 10
homing_retract_speed: 20
second_homing_speed: 15

[tmc2130 stepper_z]
#spi_speed:
spi_software_sclk_pin: PE15
spi_software_mosi_pin: PE14
spi_software_miso_pin: PA14
driver_IHOLDDELAY: 8
driver_TPOWERDOWN: 0
driver_TBL: 1
driver_TOFF: 4
driver_HEND: 7
driver_HSTRT: 0
driver_PWM_AUTOSCALE: True
driver_PWM_FREQ: 1
driver_PWM_GRAD: 4
driver_PWM_AMPL: 128
sense_resistor: 0.110
cs_pin: PD0
run_current: 1
hold_current: 0.60
interpolate: True
stealthchop_threshold: 250
diag1_pin: PC0


[extruder]
max_extrude_only_distance: 300.0
max_extrude_cross_section: 64
step_pin: PD15
dir_pin: !PD14
enable_pin: !PC7
microsteps: 16
rotation_distance: 23.0890 
full_steps_per_rotation: 200
nozzle_diameter: 0.400
filament_diameter: 1.750
gear_ratio: 50:17
heater_pin: PB3
pressure_advance: 0.195500
pressure_advance_smooth_time: 0.04
sensor_type: Generic 3950 
sensor_pin: PA2
control = pid
pid_kp = 40.403
pid_ki = 3.325
pid_kd = 122.725
min_extrude_temp: 170
min_temp: 0
max_temp: 275
max_power: 1.0

[tmc2130 extruder]
#spi_speed:
spi_software_sclk_pin: PE15
spi_software_mosi_pin: PE14
spi_software_miso_pin: PA14
driver_IHOLDDELAY: 8
driver_TPOWERDOWN: 0
driver_TBL: 1
driver_TOFF: 4
driver_HEND: 7
driver_HSTRT: 0
driver_PWM_AUTOSCALE: True
driver_PWM_FREQ: 1
driver_PWM_GRAD: 4
driver_PWM_AMPL: 128
sense_resistor: 0.110
cs_pin: PC6
run_current: 0.8
hold_current: 0.45
interpolate: True
stealthchop_threshold: 250
diag1_pin: PC2

[probe]
pin: ^!PC0
x_offset: 0
y_offset: 24
z_offset = 7.25 
speed: 15
samples: 2
sample_retract_dist: 5
lift_speed: 30
samples_result: median
samples_tolerance: 0.100
samples_tolerance_retries: 3


#[bltouch]
#sensor_pin: ^PC0
#control_pin: PE5
#probe_with_touch_mode: true
#pin_up_reports_not_triggered: true
#pin_up_touch_mode_reports_triggered: true
#stow_on_each_sample: False 
#x_offset: 0.0
#y_offset: -24
#z_offset: 0
#speed: 5
#lift_speed: 10
#samples: 1
#sample_retract_dist: 10
#samples_result: average


[safe_z_home]
home_xy_position: 153,143 
speed: 150
z_hop: 10
z_hop_speed: 10

[endstop_phase]

[bed_mesh]
speed: 90
horizontal_move_z: 10
mesh_min: 10,10
mesh_max: 285,275
probe_count: 8,6
algorithm: bicubic #lagrange
fade_start: 1
fade_end: 10
fade_target: 0
bicubic_tension: 0.2
mesh_pps: 2,2

[output_pin motor_power]
pin: PC13
value: 1

[heater_bed]
heater_pin: PD7
sensor_type: Generic 3950 #NTC 100K beta 3950
sensor_pin: PA1
control = pid
pid_kp = 31.130
pid_ki = 1.200
pid_kd = 201.955
min_temp: 0
max_temp: 135
max_power: 0.5

[fan]
pin: PB6


[heater_fan hotend_fan]
pin: PB4
max_power: 1.0
kick_start_time: 0.500
heater: extruder
heater_temp: 50.0
fan_speed: 1.0


[include mainsail.cfg]

[pause_resume]

[include macros.cfg]


[display]
lcd_type: st7920
cs_pin: PE9
sclk_pin: PE10
sid_pin: PB1
encoder_pins: ^PE7, ^PB2
click_pin: ^!PB0
#kill_pin: ^!<RST>
menu_timeout: 10


[output_pin beeper]
pin: PC5
pwm: True
value: 0
shutdown_value: 0
cycle_time: 0.001


[filament_switch_sensor runout_sensor]
pause_on_runout: True
#runout_gcode:
#insert_gcode:
#event_delay: 3.0
#pause_delay: 0.5
switch_pin: PC2

[gcode_arcs]
resolution: 0.05

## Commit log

2021-10-24 Add files via upload
    Marlin configuration
    [Configuration.h, Configuration_adv.h]
2022-05-08 Add files via upload
    Modified X and Z Motor Mounts to fit the 2020 and 2040 Aluminum Profile
    [X_motor_mount_b.stl, [a]_xz_tensioner.stl, [b]_xz_tensioner.stl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]
2022-05-08 Add files via upload
    (XZ) Belt Carriers on the X Gantry. Added a jointer to enhance stability and prevent warping parts.
    [xz_block_left_a.stl, xz_block_left_b.stl, xz_block_right_a.stl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]
2022-05-08 Add files via upload
    Modified upper XZ Belt guides to fit with 2020/2040 Aluminum Profile
    [Bearings_Mount_Left.stl, Bearings_Mount_Right.stl, XZ_Block_Left.stl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]
2022-05-08 Add files via upload
    An Alternative stronger (and much cheaper) Counterweight.
    I bought it from Aliexpress https://www.aliexpress.com/item/4001346125084.html
    Make sure to choose the 1100G Pulling force.
    [Key-Back_Alternative.stl]
2025-03-24 CAD Files
    [SW_Motor_Mount.f3d]

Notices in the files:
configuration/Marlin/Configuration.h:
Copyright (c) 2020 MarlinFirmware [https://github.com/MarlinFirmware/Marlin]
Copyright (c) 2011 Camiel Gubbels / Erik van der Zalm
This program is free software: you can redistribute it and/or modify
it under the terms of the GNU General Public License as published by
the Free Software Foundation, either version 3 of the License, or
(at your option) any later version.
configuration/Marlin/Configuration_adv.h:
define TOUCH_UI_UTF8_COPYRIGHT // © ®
